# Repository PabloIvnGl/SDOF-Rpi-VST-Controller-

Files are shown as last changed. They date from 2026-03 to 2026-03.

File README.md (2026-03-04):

# SDOF-Rpi-VST-Controller-
MIDI class compliant controller VST host based on RaspberryPi 5 SBC.  

Este repositorio contiene todos los archivos correspondientes al proyecto "SDOF DELAY CONTROL"  
Este consiste en un procesador digital de efectos de audio pensado para trabajar junto con una
interface de audio.  
El procesador esta basado en una computadora de una sola placa modelo RasapberryPi 5 de 8Gb de memoria
y un cpu arm de 2.4ghz, para procesos digitales, un microcontrolador sparkfun promicro permite su control
y consolida una superficie MIDI class compliant USB incorpora además una pantalla táctil para su interacción
con el sistema operativo Linux. En un futuro el poyecto pretende compilar una distribución propia de Linux para ejecutar
unicamente una estacion digital de audio. Actualmente se utiliza la distribución "Debian" y el daw "Waveform traktion"  

Promicro9cc4noteMEMORIA  

SDOFDELAYCONTROL CASE v14 2

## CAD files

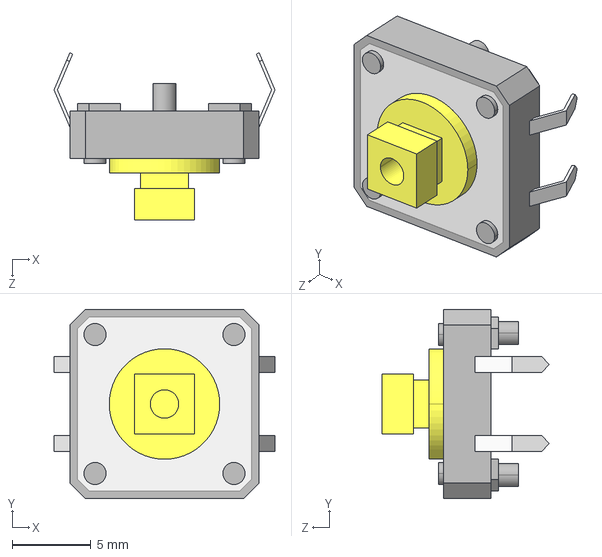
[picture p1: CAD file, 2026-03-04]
KiCatFiles/SDOFDelayControl8cc4note/STEP3D/OMRON B3F 12mm TACT SWITCH.STEP
14.0 x 12.0 x 10.6 mm

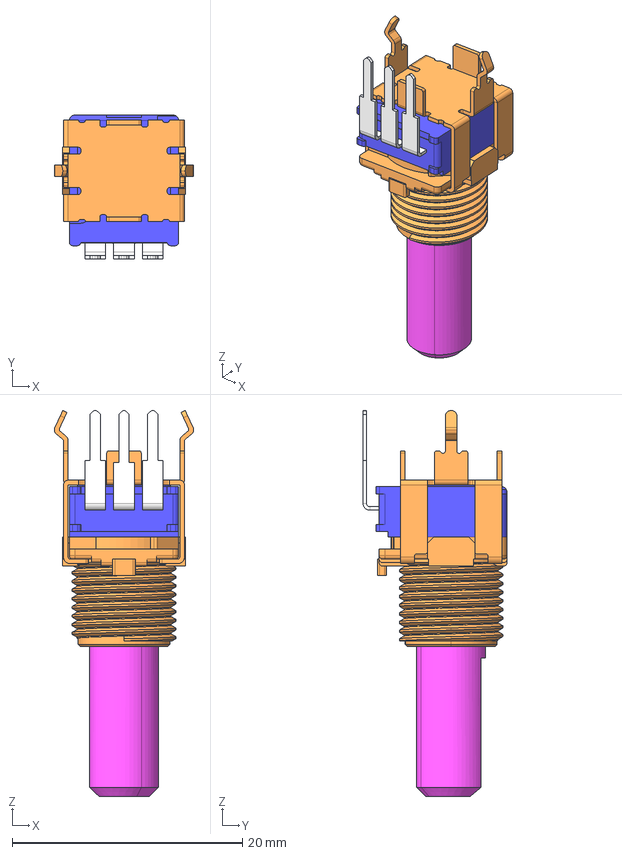
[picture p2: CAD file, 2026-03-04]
KiCatFiles/SDOFDelayControl8cc4note/STEP3D/ALPSRK09 step.stp
12.1 x 12.5 x 33.5 mm

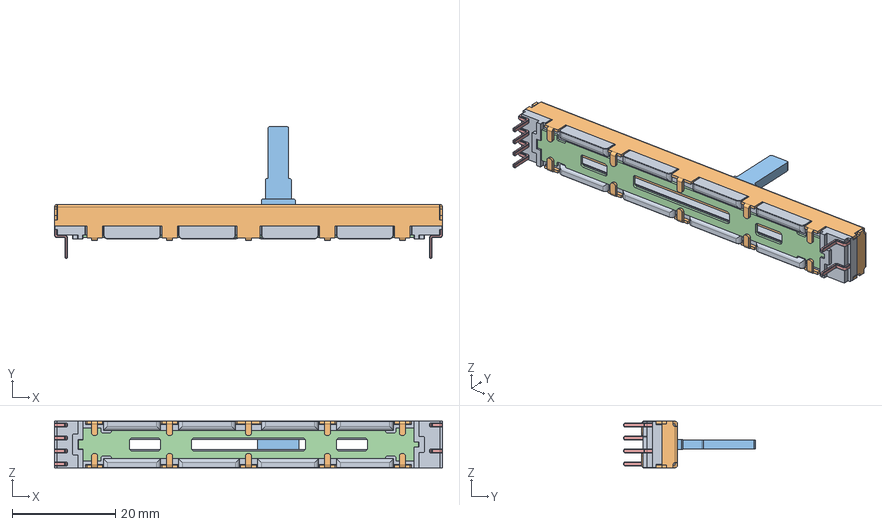
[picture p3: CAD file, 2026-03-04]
KiCatFiles/SDOFDelayControl8cc4note/STEP3D/B103 75mm FADER stp.stp
75.0 x 25.4 x 9.00 mm
SLIDE_POTENTIOMETER_BODY
SLIDE_POTENTIOMETER_COVER
SLIDE_POTENTIOMETER_BAR
SLIDE_POTENTIOMETER_PLATE
SLIDE_POTENTIOMETER_PIN x 6

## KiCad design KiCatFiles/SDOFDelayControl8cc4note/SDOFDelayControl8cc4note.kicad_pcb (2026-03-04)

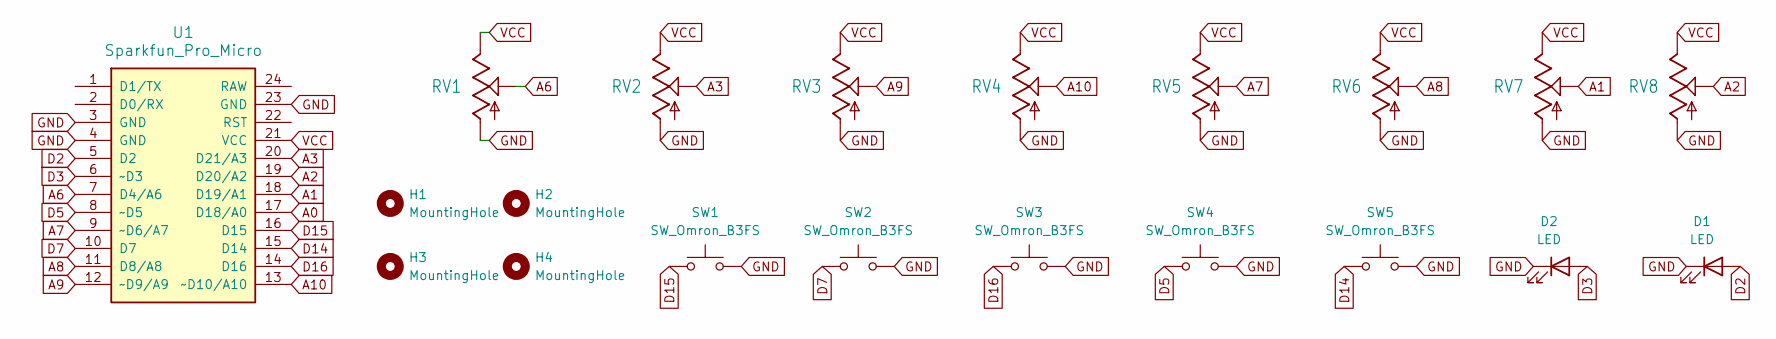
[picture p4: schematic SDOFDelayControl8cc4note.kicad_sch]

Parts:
D1, D2: LED; LED_D3.0mm
H1, H2, H3, H4: MountingHole; MountingHole_3mm
RV1, RV2, RV3, RV4: PotAlpsRK09RV09
RV5, RV6, RV7, RV8: B10375mmBehringer
SW1, SW2, SW3, SW4, SW5: SW_Omron_B3FS; Omron_B3F
U1: Sparkfun_Pro_Micro

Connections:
A0: U1.17 (D18/A0)
A1: RV7.2, U1.18 (D19/A1)
A2: RV8.2, U1.19 (D20/A2)
A3: RV2.2, U1.20 (D21/A3)
A6: RV1.2, U1.7 (D4/A6)
A7: RV5.2, U1.9 (~D6/A7)
A8: RV6.2, U1.11 (D8/A8)
A9: RV3.2, U1.12 (~D9/A9)
A10: RV4.2, U1.13 (~D10/A10)
D2: D1.2 (A), U1.5 (D2)
D3: D2.2 (A), U1.6 (~D3)
D5: SW4.1, U1.8 (~D5)
D7: SW2.1, U1.10 (D7)
D14: SW5.1, U1.15 (D14)
D15: SW1.1, U1.16 (D15)
D16: SW3.1, U1.14 (D16)
GND: D1.1 (K), D2.1 (K), RV1.1, RV2.1, RV3.1, RV4.1, RV5.1, RV6.1, RV7.1, RV8.1, SW1.2, SW2.2, SW3.2, SW4.2, SW5.2, U1.3 (GND), U1.4 (GND), U1.23 (GND)
VCC: RV1.3, RV2.3, RV3.3, RV4.3, RV5.3, RV6.3, RV7.3, RV8.3, U1.21 (VCC)

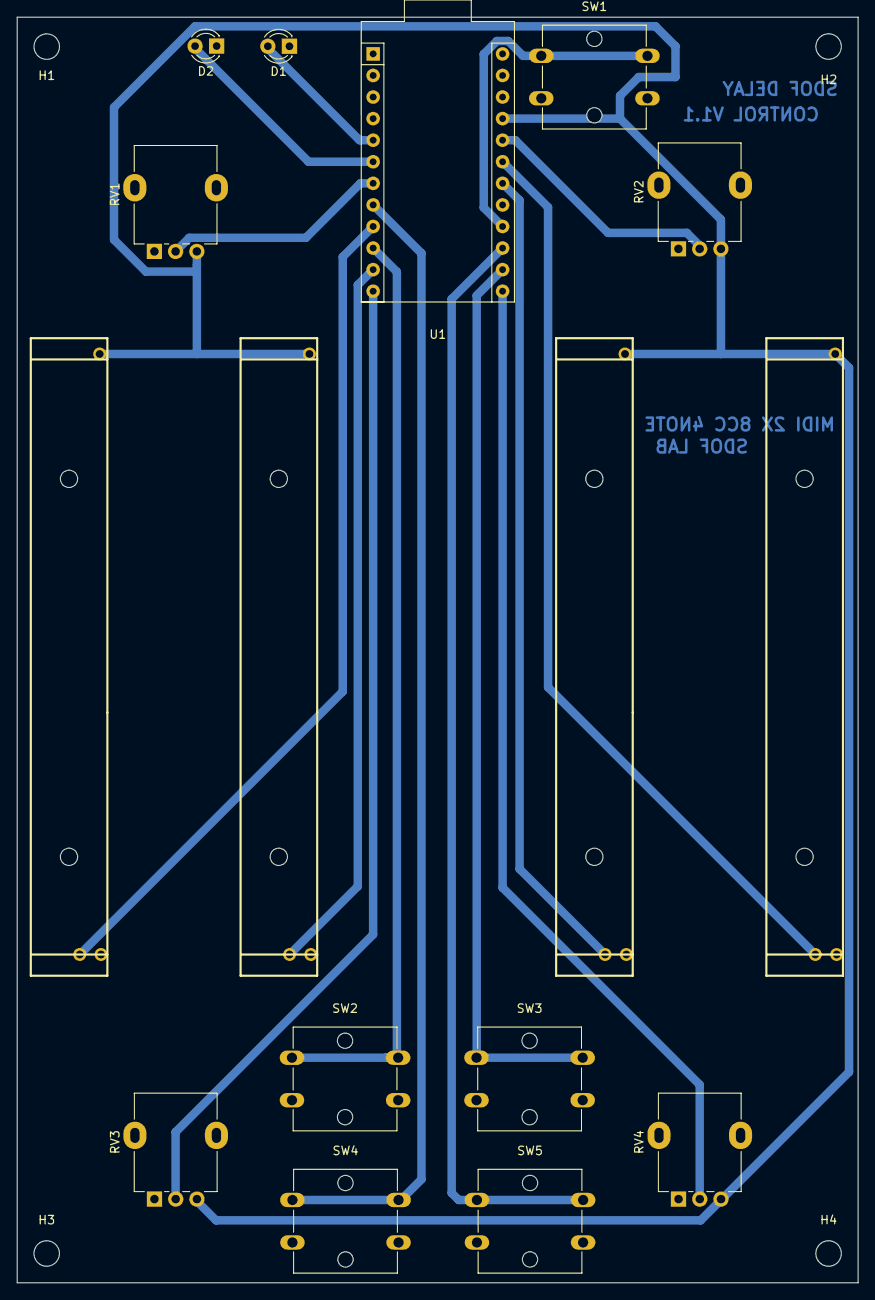
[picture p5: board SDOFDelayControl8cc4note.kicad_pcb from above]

Board: 2 copper layers, 99.0 x 149.0 mm, 20 parts (0 on the bottom side), 17 nets.

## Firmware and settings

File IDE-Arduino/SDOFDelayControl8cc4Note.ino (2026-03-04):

///////////-------------- CODIGO SDOF DELAY CONTROL MIDI USB 2X 8cc 4note ----------------////////////// PABLO GUTIERREZ LEGENT 2025
///////////---------Este codigo compila la version V1.1 del controlador midi SDOFDELAY --///////////////
///////////---------SDOFDELAYCONTROL es una superficie de control midi con dos paginas --///////////////
///////////---------MIDI de eventos midi,ocho ControlChange(CC) y  cuatro MidiNote(NOTE)-///////////////  
#include "MIDIUSB.h"               // Librería MIDI por USB para sparkfun promicro
#include <ResponsiveAnalogRead.h>  // Librería ResponsiveAnalogRead  https://github.com/dxinteractive/ResponsiveAnalogRead para lectura de pot

const int N_POTS = 8;     // Número de potenciómetros
const int N_BOT  = 4;     // Número de botones
 

const int midipageBotPIN = 15;   // Pin del botón de cambio de página MIDI
int ledmidipagePIN = 2;          // Pin del LED indicador de página MIDI
int onLedPIN       = 3;          // Pin del LED de encendido y parpadeo de nota MIDI



int botPin[N_BOT]   = { 7, 16,  5, 14};       // Pines digitales de los botones
int botnote[N_BOT]  = {36, 37, 38, 39};     // Notas MIDI asignadas a cada botón


int potPin[N_POTS] = {  A6, A3, A9, A0, A7, A8, A1, A2};  // Pines analógicos para los potenciómetros
int potCC[N_POTS] =  {   1,  2,  3,  4,  5,  6,  7,  8};  // Números de Control Change (CC) MIDI asignados a cada potenciómetro

int potReading[N_POTS] = { 0 };  // Inicializacion lecturas crudas de los potenciómetros
int potState[N_POTS] = { 0 };    // Inicializacion valores suavizados de los potenciómetros
int potPState[N_POTS] = { 0 };   // Inicializacion valores anteriores de los potenciómetros

int midiState[N_POTS] = { 0 };    // Inicializacion valores MIDI mapeados actuales
int midiPState[N_POTS] = { 0 };   // Inicializacion valores MIDI mapeados anteriores

int botState[N_BOT]          = {0};
bool botpreviousState[N_BOT] = {false, false, false, false};
bool swPressed[N_BOT]        = {false, false, false, false};
bool swPreviousState[N_BOT]  = {false, false, false, false};
bool swledState[N_BOT]       = {false, false, false, false};

const byte potThreshold = 20;           // Umbral mínimo de cambio para detectar movimiento del potenciómetro
const int POT_TIMEOUT = 300;            // Tiempo de espera (ms) para detectar que el potenciómetro dejó de moverse
unsigned long pPotTime[N_POTS] = { 0 };  // Tiempo del último cambio detectado en cada potenciómetro
unsigned long potTimer[N_POTS] = { 0 };  // Tiempo transcurrido desde el último cambio en cada potenciómetro

byte POT_CH = 0;  // Canal MIDI para los potenciómetros
byte BOT_CH = 0;  // Canal MIDI para los botones
float snapMultiplier = 0.01;                      // Multiplicador de suavizado para las lecturas analógicas
ResponsiveAnalogRead responsivePot[N_POTS] = {};  // Arreglo de objetos ResponsiveAnalogRead (se inicializa en Setup)


// ---- BOTÓN DE CAMBIO DE PÁGINA MIDI ----
bool midibuttonPressed = false;
bool midibuttonPreviousState = false;
bool midiledState = false;  // Estado del LED de página MIDI (encendido/apagado)


void setup() {
  

  Serial.begin(9600);  // Inicializa la comunicación serie para depuración
  
  pinMode(midipageBotPIN, INPUT_PULLUP); // Botón de página MIDI como entrada con pull-up interno
  pinMode(ledmidipagePIN, OUTPUT);       // LED de página MIDI como salida
  pinMode(onLedPIN      , OUTPUT);       // LED de encendido como salida

  // blink de encendido secuencia de parpadeo de bienvenida al encender 
  digitalWrite(onLedPIN, HIGH);
      delay(500);
      digitalWrite(onLedPIN, LOW);
      delay(90);
  digitalWrite(onLedPIN, HIGH);
      delay(90);
  digitalWrite(onLedPIN, LOW);

      
  for(int i = 0; i < N_BOT; i++) {        // Configura los pines de botones con pull-up interno
    pinMode(botPin[i], INPUT_PULLUP);
  }

  for (int i = 0; i < N_POTS; i++) {
    responsivePot[i] = ResponsiveAnalogRead(0, true, snapMultiplier);  // Inicializa los potenciómetros con suavizado
    responsivePot[i].setAnalogResolution(1023);                        // Resolución analógica de 10 bits (0-1023)
  }
}

void loop() {
  // Bucle principal: se ejecuta repetidamente


  // ---- LECTURA DE BOTONES MIDI (NOTAS) ----
  for(int i = 0; i < N_BOT; i++) {
    botState[i] = digitalRead(botPin[i]);
  }

  // ---- BOTÓN DE CAMBIO DE PÁGINA MIDI ----
  int midibotState = digitalRead(midipageBotPIN);

  if (midibotState == LOW && !midibuttonPreviousState) { // Detecta (botón recién presionado)
    midibuttonPressed = true;
  } else {
    midibuttonPressed = false;
  }

  midibuttonPreviousState = (midibotState == LOW);    // Actualiza el estado anterior del botón de página

  if (midibuttonPressed) { // Si se presionó el botón, alterna el canal MIDI entre 0 y 9
    POT_CH = (POT_CH == 0) ? 9 : 0;
    BOT_CH = (BOT_CH == 0) ? 9 : 0; 
    
    midiledState = !midiledState;                                      // Alterna el estado del LED de página
    digitalWrite(ledmidipagePIN, midiledState ? HIGH : LOW);          // Enciende o apaga el LED de página
  }
  
  // ---- ENVÍO DE NOTAS MIDI POR BOTONES ----
  for(int i = 0; i < (N_BOT); i++) {

    if (botState[i] == LOW && !swPreviousState[i]) {  // Detecta (botón recién presionado)
      swPressed[i] = true;
    } else {
      swPressed[i] = false;
    }

    swPreviousState[i] = (botState[i] == LOW);  // Actualiza el estado anterior de cada botón

    if(swPressed[i]) {        // Al presionar: envía Note On y parpadea el LED de encendido
      
      noteOn (BOT_CH, botnote[i], 127);
      MidiUSB.flush();

      //swledState[i] = !swledState[i];
      digitalWrite(onLedPIN, HIGH);
      delay(50);
      digitalWrite(onLedPIN, LOW);
      delay(10);
    }
    else {                    // Al soltar: envía Note Off
      noteOff (BOT_CH, botnote[i], 127);
      MidiUSB.flush();
    } 
  }


  // ---- LECTURA Y ENVÍO DE CONTROL CHANGE POR POTENCIÓMETROS ----
  for (int i = 0; i < N_POTS; i++) {

    potReading[i] = analogRead(potPin[i]);          // Lee el valor crudo del potenciómetro
    responsivePot[i].update(potReading[i]);          // Actualiza el suavizado del potenciómetro
    potState[i] = responsivePot[i].getValue();       // Obtiene el valor suavizado
    midiState[i] = map(potState[i], 0, 1023, 0, 128); // Mapea el valor al rango MIDI (0-127)

    int potVar = abs(potState[i] - potPState[i]);   // Calcula el cambio absoluto del potenciómetro

    if (potVar > potThreshold) {
      pPotTime[i] = millis();  // Registra el momento del último cambio significativo
    }

    potTimer[i] = millis() - pPotTime[i];  // Calcula el tiempo transcurrido desde el último cambio

    if (potTimer[i] < POT_TIMEOUT) {
      if (midiState[i] != midiPState[i]) {
        
        controlChange(POT_CH, potCC[i], midiState[i]);  // Envía el mensaje MIDI Control Change (canal, CC, valor)
        MidiUSB.flush();                                 //  salida MIDI

        // Imprime en el monitor serie para depuración
        Serial.print("Pot ");
        Serial.print(i);
        Serial.print(" | ");
        Serial.print("PotState: ");
        Serial.print(potState[i]);
        Serial.print(" -  midiState: ");
        Serial.println(midiState[i]);

        midiPState[i] = midiState[i];  // Actualiza el estado MIDI anterior
      }
      potPState[i] = potState[i];  // Actualiza el valor anterior del potenciómetro
    }
  }
}


// ---- FUNCIONES MIDI PARA ARDUINO (PRO) MICRO CON LIBRERÍA MIDIUSB ----

void noteOn(byte channel, byte pitch, byte velocity) {
  // Envía un mensaje Note On: canal, nota, velocidad
  midiEventPacket_t noteOn = { 0x09, 0x90 | channel, pitch, velocity };
  MidiUSB.sendMIDI(noteOn);
}

void noteOff(byte channel, byte pitch, byte velocity) {
  // Envía un mensaje Note Off: canal, nota, velocidad
  midiEventPacket_t noteOff = { 0x08, 0x80 | channel, pitch, velocity };
  MidiUSB.sendMIDI(noteOff);
}

void controlChange(byte channel, byte control, byte value) {
  // Envía un mensaje Control Change: canal, número de control, valor
  midiEventPacket_t event = { 0x0B, 0xB0 | channel, control, value };
  MidiUSB.sendMIDI(event);
}
